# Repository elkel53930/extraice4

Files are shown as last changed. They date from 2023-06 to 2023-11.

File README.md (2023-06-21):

# ExtraICE4

ExtraICE4 is a competition robot called Micromouse.

For more information on Micromouse competitions, please see the [website](https://www.ntf.or.jp/) of the New Technology Foundation.

## Hardware

- 3DCAD data by Fusion360 : https://t.co/qPmjVBnEnc
  - STL file for 3D printing : under `mecha` directory
- Schematic and PCB design by KiCad7 : under `kicad/extraice` directory

## Firmware

The firmware is written by Rust language.

See [The Rust on ESP Book](https://esp-rs.github.io/book/) for instructions on how to set up the development environment.

The firmware is located under `fsw` directory. This directory is a sub-module, which is actually the micromouse-esp32 repository.

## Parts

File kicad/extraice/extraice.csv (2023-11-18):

# | Reference | Qty | Value | Footprint | DNP
1 | C1, C10 | 2 | 1608 35V 1uF | Capacitor_SMD:C_0603_1608Metric
2 | C2, C18, C21 | 3 | 2012 35V 10uF | Capacitor_SMD:C_0805_2012Metric
3 | C3, C5, C7, C8, C9, C12, C14, C15, C16, C19 | 10 | 0603 50V 0.1uF | Capacitor_SMD:C_0201_0603Metric
4 | C4 | 1 | 3225 25V 22uF | Capacitor_SMD:C_1210_3225Metric
5 | C11, C13 | 2 | 1005 N/M | Capacitor_SMD:C_0402_1005Metric
6 | D1, D2, D3, D4 | 4 | OSI5FU3A11C | Micromouse:OSI5FU3A11C
7 | D5 | 1 | 1608 R LED | LED_SMD:LED_0603_1608Metric
8 | D6 | 1 | 1608 G LED | LED_SMD:LED_0603_1608Metric
9 | D7 | 1 | 1608 B LED | LED_SMD:LED_0603_1608Metric
10 | H1, H2, H3, H4 | 4 | Φ1.4 | Micromouse:Hole1.4
11 | J1 | 1 | Conn_01x02 | Micromouse:B2B-ZH
12 | J3, J6 | 2 | EncSide | Micromouse:EncoderTerminal
13 | J4, J7 | 2 | MainSide | Micromouse:EncoderTerminal
14 | J5 | 1 | Conn_01x05 | Connector_PinHeader_1.27mm:PinHeader_1x05_P1.27mm_Vertical
15 | J8, J9, J10 | 3 | Conn_01x02 | Micromouse:MotorPad
16 | Q1, Q2, Q3, Q4 | 4 | L-31ROPT1C | Micromouse:OSI5FU3A11C
17 | R1, R7, R10, R12 | 4 | 0603 470 1% | Resistor_SMD:R_0201_0603Metric
18 | R2, R8, R14, R15, R16 | 5 | 0603 10k | Resistor_SMD:R_0201_0603Metric
19 | R4, R5, R6, R9 | 4 | 0603 1k | Resistor_SMD:R_0201_0603Metric
20 | R11 | 1 | 0603 6.2 | Resistor_SMD:R_0201_0603Metric
21 | R13 | 1 | 0603 22k | Resistor_SMD:R_0201_0603Metric
22 | SW1 | 1 | PCM12SMTR | Button_Switch_SMD:SW_SPDT_PCM12
23 | SW2 | 1 | B3U-1000P | Button_Switch_SMD:SW_SPST_B3U-1000P
24 | U1 | 1 | DG2034EDN | Library:QFN-12-1EP_3x3mm_P0.5_EP1.15x1.15
25 | U2 | 1 | BCR421 | Library:SOT-26
26 | U3 | 1 | MUN12AD01-SG | Library:MUN12AD01-SG
27 | U4 | 1 | MB85RC64TA | Library:LCC-8P-M04
28 | U5 | 1 | LSM6DSR | Package_LGA:Bosch_LGA-14_3x2.5mm_P0.5mm
29 | U6 | 1 | XC6221B302GR | Package_TO_SOT_SMD:SOT-23-5
30 | U7 | 1 | ESP32-S3-FN8 | Package_DFN_QFN:QFN-56-1EP_7x7mm_P0.4mm_EP4x4mm
31 | U8, U12 | 2 | AS5047D | Package_SO:TSSOP-14_4.4x5mm_P0.65mm
32 | U9, U10, U11 | 3 | DRV8837C | Package_SON:WSON-8-1EP_2x2mm_P0.5mm_EP0.9x1.6mm
33 | X1 | 1 | 830108208709 | Oscillator:Oscillator_SMD_ECS_2520MV-xxx-xx-4Pin_2.5x2.0mm

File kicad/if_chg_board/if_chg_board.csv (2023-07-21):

Source: | C:\dev\extraice4\kicad\if_chg_board\if_chg_board.kicad_sch
Date: | 2023/07/21 8:57:58
Tool: | Eeschema (7.0.0)
Generator: | C:\Program Files\KiCad\7.0\bin\scripting\plugins/bom_csv_grouped_by_value.py
Component Count: | 47
Collated Components:
Item | Qty | Reference(s) | Value | LibPart | Footprint | Datasheet | DNP
1 | 2 | C1, C4 | 3225 22uF | Device:C_Small | Capacitor_SMD:C_1210_3225Metric | ~
2 | 4 | C2, C3, C5, C6 | 1608 4.7u | Device:C_Small | Capacitor_SMD:C_0603_1608Metric | ~
3 | 3 | C7, C8, C9 | 1608 0.1u | Device:C_Small | Capacitor_SMD:C_0603_1608Metric | ~
4 | 2 | D1, D2 | LED RED | Device:LED | LED_SMD:LED_0603_1608Metric | ~
5 | 1 | D3 | SP0503BAHT | Power_Protection:SP0503BAHT | Package_TO_SOT_SMD:SOT-143 | http://www.littelfuse.com/~/media/files/littelfuse/technical%20resources/documents/data%20sheets/sp05xxba.pdf
6 | 1 | D4 | BAT760-7 | Device:D_Schottky | Diode_SMD:D_SOD-323 | ~
7 | 1 | D5 | LED GREEN | Device:LED | LED_SMD:LED_0603_1608Metric | ~
8 | 4 | H1, H2, H3, H4 | Φ3.2 M3 | Mechanical:MountingHole | MountingHole:MountingHole_3.2mm_M3 | ~
9 | 1 | J1 | USB_B_Micro | Connector:USB_B_Micro | Connector_USB:USB_Micro-B_Molex-105017-0001 | ~
10 | 2 | J2, J3 | B2B-ZH | Connector_Generic:Conn_01x02 | Library:B2B-ZH | ~
11 | 1 | J4 | Conn_01x05 | Connector_Generic:Conn_01x05 | Connector_PinHeader_1.27mm:PinHeader_1x05_P1.27mm_Vertical | ~
12 | 1 | J5 | B2B-ZH | Connector_Generic:Conn_01x02 | Connector_PinHeader_2.54mm:PinHeader_1x02_P2.54mm_Vertical | ~
13 | 2 | Q1, Q2 | SS8050-G | Device:Q_NPN_BEC | Package_TO_SOT_SMD:SOT-23 | ~
14 | 4 | R1, R2, R3, R4 | 1608 1.2K | Device:R | Resistor_SMD:R_0603_1608Metric | ~
15 | 2 | R5, R7 | 1608 2K | Device:R | Resistor_SMD:R_0603_1608Metric | ~
16 | 1 | R6 | 1608 0 | Device:R | Resistor_SMD:R_0603_1608Metric | ~
17 | 1 | R8 | 1608 10K NC | Device:R | Resistor_SMD:R_0603_1608Metric | ~
18 | 3 | R9, R10, R11 | 1608 10K | Device:R | Resistor_SMD:R_0603_1608Metric | ~
19 | 2 | SW1, SW2 | B3U-1000P | Switch:SW_Push | Button_Switch_SMD:SW_SPST_B3U-1000P | ~
20 | 4 | TP1, TP2, TP3, TP4 | ~ | Connector:TestPoint | TestPoint:TestPoint_Pad_D1.5mm | ~
21 | 1 | TP5 | ~ | Connector:TestPoint | Connector_PinHeader_2.54mm:PinHeader_1x01_P2.54mm_Vertical | ~
22 | 1 | U1 | AMS1117-3.3 | Regulator_Linear:AMS1117-3.3 | Package_TO_SOT_SMD:SOT-223-3_TabPin2 | http://www.advanced-monolithic.com/pdf/ds1117.pdf
23 | 2 | U2, U3 | LTC4054ES5-4.2 | Battery_Management:LTC4054ES5-4.2 | Package_TO_SOT_SMD:TSOT-23-5 | https://www.analog.com/media/en/technical-documentation/data-sheets/405442xf.pdf
24 | 1 | U4 | CP2102-GM | Interface_USB:CP2102N-Axx-xQFN28 | Package_DFN_QFN:QFN-28-1EP_5x5mm_P0.5mm_EP3.35x3.35mm | https://www.silabs.com/documents/public/data-sheets/cp2102n-datasheet.pdf

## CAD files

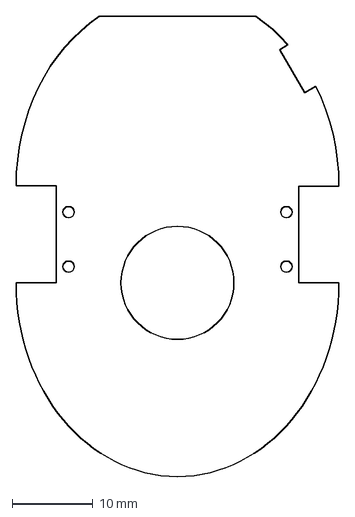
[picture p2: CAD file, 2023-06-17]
kicad/extraice/mainboard.dxf
40.0 x 57.0 mm

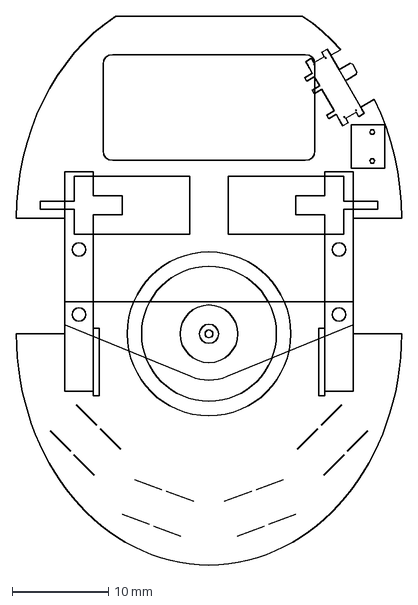
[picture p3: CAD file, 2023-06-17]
kicad/extraice/mainboard_position.dxf
40.0 x 57.0 mm

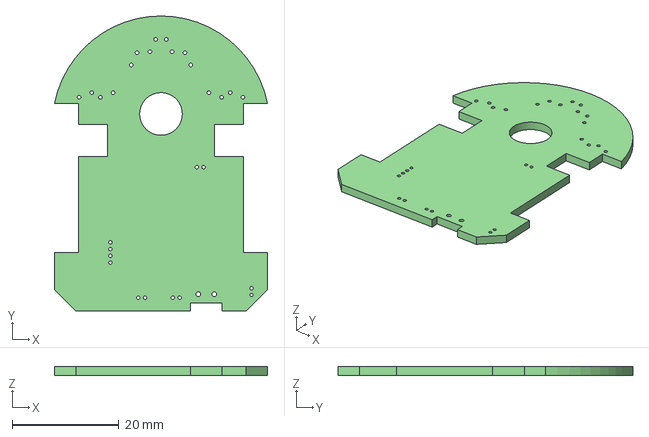
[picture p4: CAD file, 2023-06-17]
kicad/extraice/extraice.step
40.0 x 55.4 x 1.60 mm

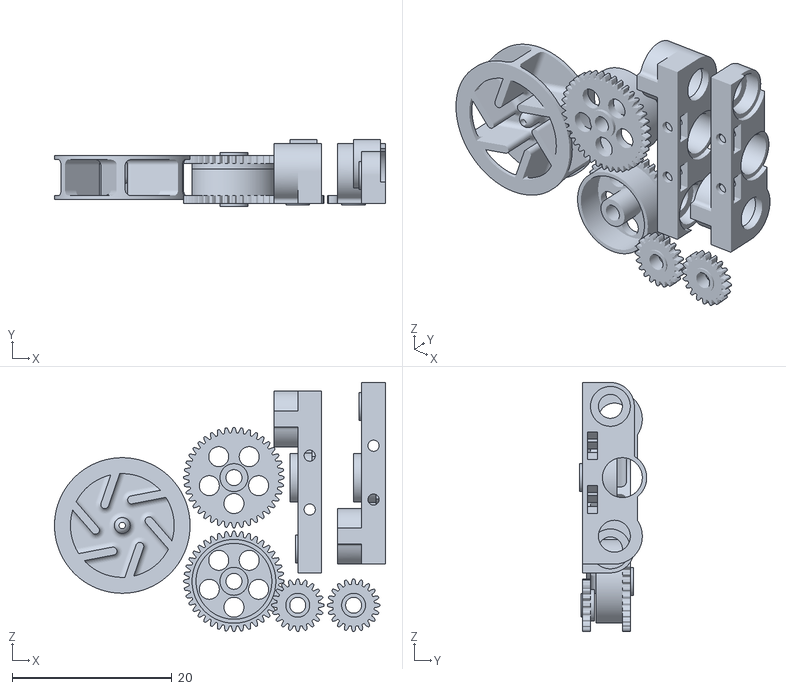
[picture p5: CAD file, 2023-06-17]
mecha/parts_set.stl
41.5 x 8.45 x 31.2

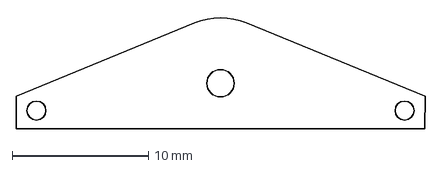
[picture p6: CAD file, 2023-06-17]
kicad/extraice/vacboard.dxf
30.0 x 8.26 mm

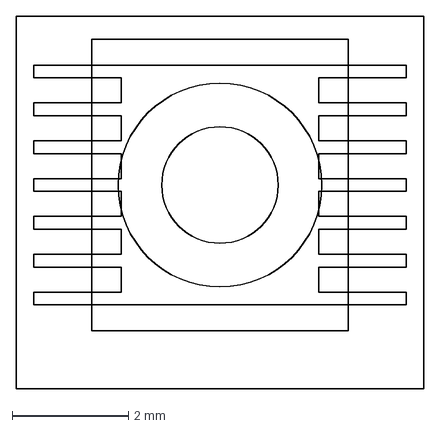
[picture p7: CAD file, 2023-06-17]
kicad/extraice/encoder.dxf
7.00 x 6.40 mm

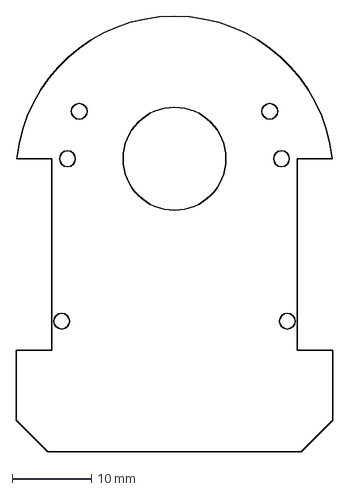
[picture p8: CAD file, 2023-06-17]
kicad/extraice/bottomboard.dxf
40.0 x 55.0 mm

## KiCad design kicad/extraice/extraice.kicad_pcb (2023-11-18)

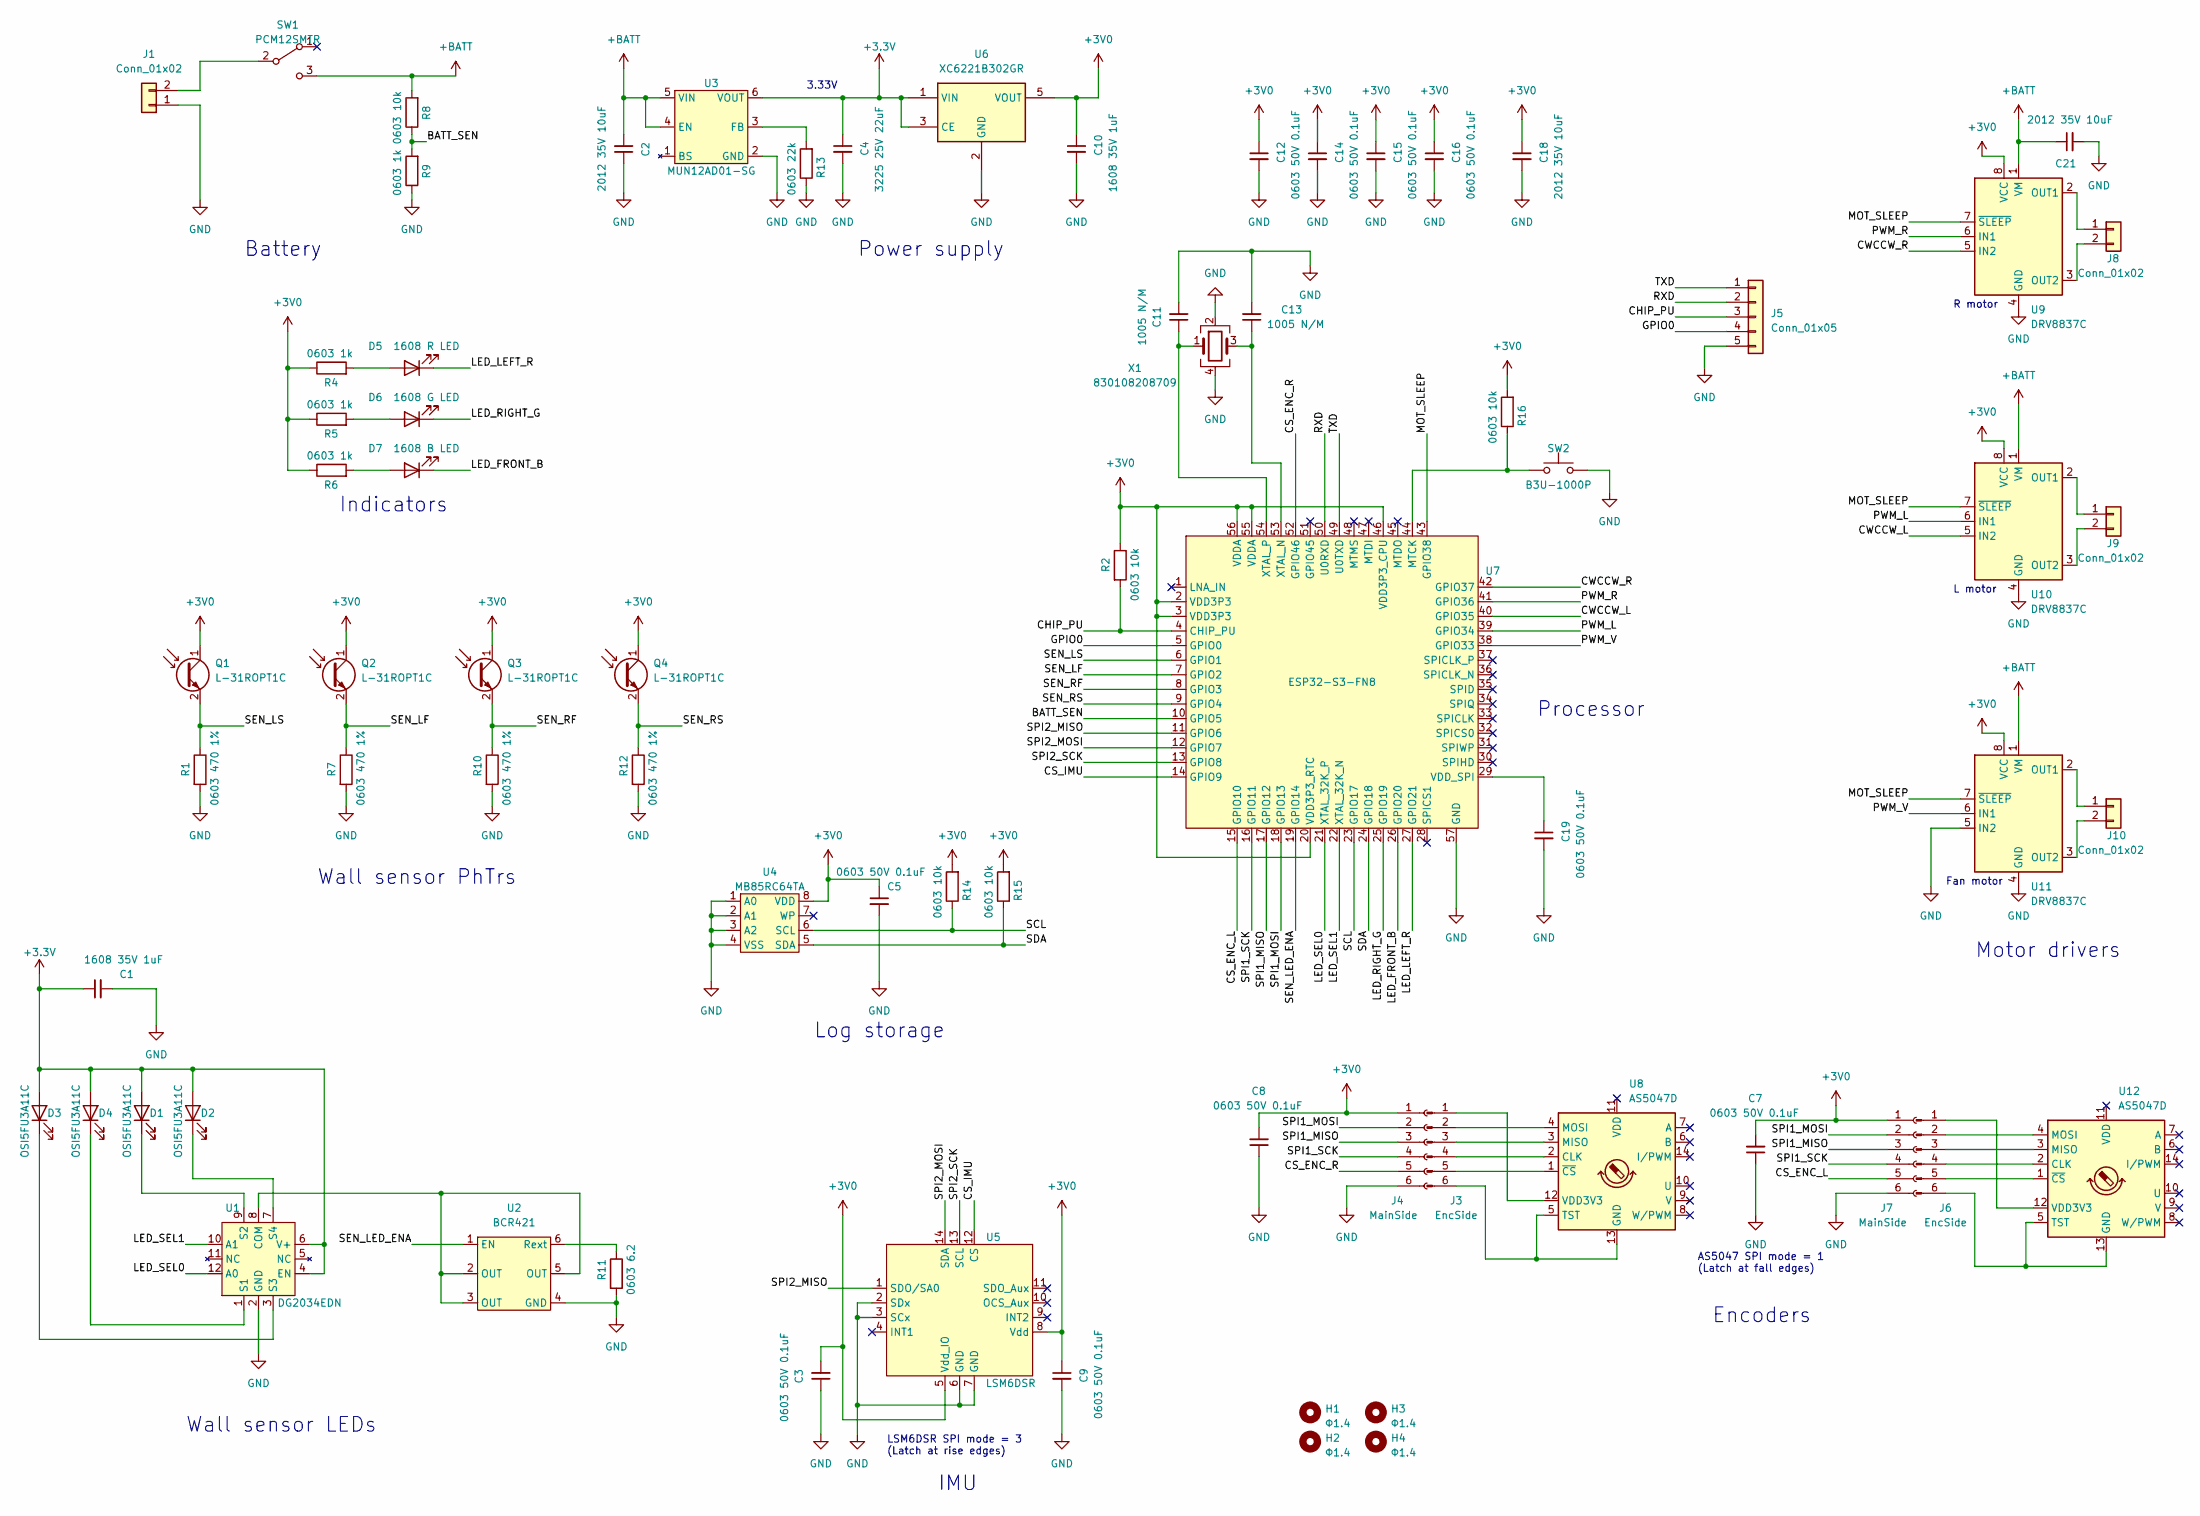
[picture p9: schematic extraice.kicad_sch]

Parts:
C1, C10: 1608 35V 1uF; C_0603_1608Metric
C2, C18, C21: 2012 35V 10uF; C_0805_2012Metric
C3, C5, C7, C8, C9, C12, C14, C15, C16, C19: 0603 50V 0.1uF; C_0201_0603Metric
C4: 3225 25V 22uF; C_1210_3225Metric
C11, C13: 1005 N/M; C_0402_1005Metric
D1, D2, D3, D4: OSI5FU3A11C
D5: 1608 R LED; LED_0603_1608Metric
D6: 1608 G LED; LED_0603_1608Metric
D7: 1608 B LED; LED_0603_1608Metric
H1, H2, H3, H4: Φ1.4; Hole1.4
J1: Conn_01x02; B2B-ZH
J3, J6: EncSide; EncoderTerminal
J4, J7: MainSide; EncoderTerminal
J5: Conn_01x05; PinHeader_1x05_P1.27mm_Vertical
J8, J9, J10: Conn_01x02; MotorPad
Q1, Q2, Q3, Q4: L-31ROPT1C; OSI5FU3A11C
R1, R7, R10, R12: 0603 470 1%; R_0201_0603Metric
R2, R8, R14, R15, R16: 0603 10k; R_0201_0603Metric
R4, R5, R6, R9: 0603 1k; R_0201_0603Metric
R11: 0603 6.2; R_0201_0603Metric
R13: 0603 22k; R_0201_0603Metric
SW1: PCM12SMTR; SW_SPDT_PCM12
SW2: B3U-1000P; SW_SPST_B3U-1000P
U1: DG2034EDN; QFN-12-1EP_3x3mm_P0.5_EP1.15x1.15
U2: BCR421; SOT-26
U3: MUN12AD01-SG
U4: MB85RC64TA; LCC-8P-M04
U5: LSM6DSR; Bosch_LGA-14_3x2.5mm_P0.5mm
U6: XC6221B302GR; SOT-23-5
U7: ESP32-S3-FN8; QFN-56-1EP_7x7mm_P0.4mm_EP4x4mm
U8, U12: AS5047D; TSSOP-14_4.4x5mm_P0.65mm
U9, U10, U11: DRV8837C; WSON-8-1EP_2x2mm_P0.5mm_EP0.9x1.6mm
X1: 830108208709; Oscillator_SMD_ECS_2520MV-xxx-xx-4Pin_2.5x2.0mm

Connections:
+3.3V: C1.1, C4.1, D1.2 (A), D2.2 (A), D3.2 (A), D4.2 (A), U1.4 (EN), U1.6 (V+), U3.6 (VOUT), U6.1 (VIN), U6.3 (CE)
+3V0: C3.2, C5.1, C7.2, C8.2, C9.1, C10.1, C12.1, C14.1, C15.1, C16.1, C18.1, J4.1, J7.1, Q1.1 (C), Q2.1 (C), Q3.1 (C), Q4.1 (C), R2.1, R4.1, R5.1, R6.1, R14.2, R15.2, R16.2, U4.8 (VDD), U5.5 (Vdd_IO), U5.8 (Vdd), U6.5 (VOUT), U7.2 (VDD3P3), U7.3 (VDD3P3), U7.20 (VDD3P3_RTC), U7.46 (VDD3P3_CPU), U7.55 (VDDA), U7.56 (VDDA), U9.8 (VCC), U10.8 (VCC), U11.8 (VCC)
+BATT: C2.2, C21.1, R8.2, SW1.3 (C), U3.4 (EN), U3.5 (VIN), U9.1 (VM), U10.1 (VM), U11.1 (VM)
/BATT_SEN: R8.1, R9.2, U7.10 (GPIO5)
/CHIP_PU: J5.3, R2.2, U7.4 (CHIP_PU)
/CS_ENC_L: J7.5, U7.15 (GPIO10)
/CS_ENC_R: J4.5, U7.52 (GPIO46)
/CS_IMU: U5.12 (CS), U7.14 (GPIO9)
/CWCCW_L: U7.40 (GPIO35), U10.5 (IN2)
/CWCCW_R: U7.42 (GPIO37), U9.5 (IN2)
/GPIO0: J5.4, U7.5 (GPIO0)
/LED_FRONT_B: D7.1 (K), U7.26 (GPIO20)
/LED_LEFT_R: D5.1 (K), U7.27 (GPIO21)
/LED_RIGHT_G: D6.1 (K), U7.25 (GPIO19)
/LED_SEL0: U1.12 (A0), U7.21 (XTAL_32K_P)
/LED_SEL1: U1.10 (A1), U7.22 (XTAL_32K_N)
/MOT_SLEEP: U7.43 (GPIO38), U9.7 (~SLEEP), U10.7 (~SLEEP), U11.7 (~SLEEP)
/PWM_L: U7.39 (GPIO34), U10.6 (IN1)
/PWM_R: U7.41 (GPIO36), U9.6 (IN1)
/PWM_V: U7.38 (GPIO33), U11.6 (IN1)
/RXD: J5.2, U7.50 (U0RXD)
/SCL: R14.1, U4.6 (SCL), U7.23 (GPIO17)
/SDA: R15.1, U4.5 (SDA), U7.24 (GPIO18)
/SEN_LED_ENA: U2.1 (EN), U7.19 (GPIO14)
/SEN_LF: Q2.2 (E), R7.1, U7.7 (GPIO2)
/SEN_LS: Q1.2 (E), R1.1, U7.6 (GPIO1)
/SEN_RF: Q3.2 (E), R10.1, U7.8 (GPIO3)
/SEN_RS: Q4.2 (E), R12.1, U7.9 (GPIO4)
/SPI1_MISO: J4.3, J7.3, U7.17 (GPIO12)
/SPI1_MOSI: J4.2, J7.2, U7.18 (GPIO13)
/SPI1_SCK: J4.4, J7.4, U7.16 (GPIO11)
/SPI2_MISO: U5.1 (SDO/SA0), U7.11 (GPIO6)
/SPI2_MOSI: U5.14 (SDA), U7.12 (GPIO7)
/SPI2_SCK: U5.13 (SCL), U7.13 (GPIO8)
/TXD: J5.1, U7.49 (U0TXD)
GND: C1.2, C2.1, C3.1, C4.2, C5.2, C7.1, C8.1, C9.2, C10.2, C11.2, C12.2, C13.2, C14.2, C15.2, C16.2, C18.2, C19.2, C21.2, J1.1, J4.6, J5.5, J7.6, R1.2, R7.2, R9.1, R10.2, R11.2, R12.2, R13.1, SW2.2, U1.2 (GND), U2.4 (GND), U3.2 (GND), U4.1 (A0), U4.2 (A1), U4.3 (A2), U4.4 (VSS), U5.2 (SDx), U5.3 (SCx), U5.6 (GND), U5.7 (GND), U6.2 (GND), U7.57 (GND), U9.4 (GND), U9.9 (GND), U10.4 (GND), U10.9 (GND), U11.4 (GND), U11.5 (IN2), U11.9 (GND), X1.2, X1.4
unnamed: D1.1 (K), U1.9 (S2)
unnamed: D2.1 (K), U1.7 (S4)
unnamed: D3.1 (K), U1.3 (S3)
unnamed: D4.1 (K), U1.1 (S1)
unnamed: D5.2 (A), R4.2
unnamed: D6.2 (A), R5.2
unnamed: D7.2 (A), R6.2
unnamed: J1.2, SW1.2 (B)
unnamed: J3.1, U8.12 (VDD3V3)
unnamed: J3.2, U8.4 (MOSI)
unnamed: J3.3, U8.3 (MISO)
unnamed: J3.4, U8.2 (CLK)
unnamed: J3.5, U8.1 (~CS)
unnamed: J3.6, U8.5 (TST), U8.13 (GND)
unnamed: J6.1, U12.12 (VDD3V3)
unnamed: J6.2, U12.4 (MOSI)
unnamed: J6.3, U12.3 (MISO)
unnamed: J6.4, U12.2 (CLK)
unnamed: J6.5, U12.1 (~CS)
unnamed: J6.6, U12.5 (TST), U12.13 (GND)
unnamed: J8.1, U9.2 (OUT1)
unnamed: J8.2, U9.3 (OUT2)
unnamed: J9.1, U10.2 (OUT1)
unnamed: J9.2, U10.3 (OUT2)
unnamed: J10.1, U11.2 (OUT1)
unnamed: J10.2, U11.3 (OUT2)
unnamed: U1.8 (COM), U2.2 (OUT), U2.3 (OUT), U2.5 (OUT)
unnamed: R11.1, U2.6 (Rext)
unnamed: R13.2, U3.3 (FB)
unnamed: R16.1, SW2.1, U7.44 (MTCK)
unnamed: C19.1, U7.29 (VDD_SPI)
unnamed: C13.1, U7.53 (XTAL_N), X1.3
unnamed: C11.1, U7.54 (XTAL_P), X1.1

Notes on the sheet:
Wall sensor LEDs
L motor
R motor
Indicators
Motor drivers
Power supply
3.33V
LSM6DSR SPI mode = 3 (Latch at rise edges)
Wall sensor PhTrs
Processor
AS5047 SPI mode = 1 (Latch at fall edges)
Log storage
Battery
Encoders
IMU
Fan motor

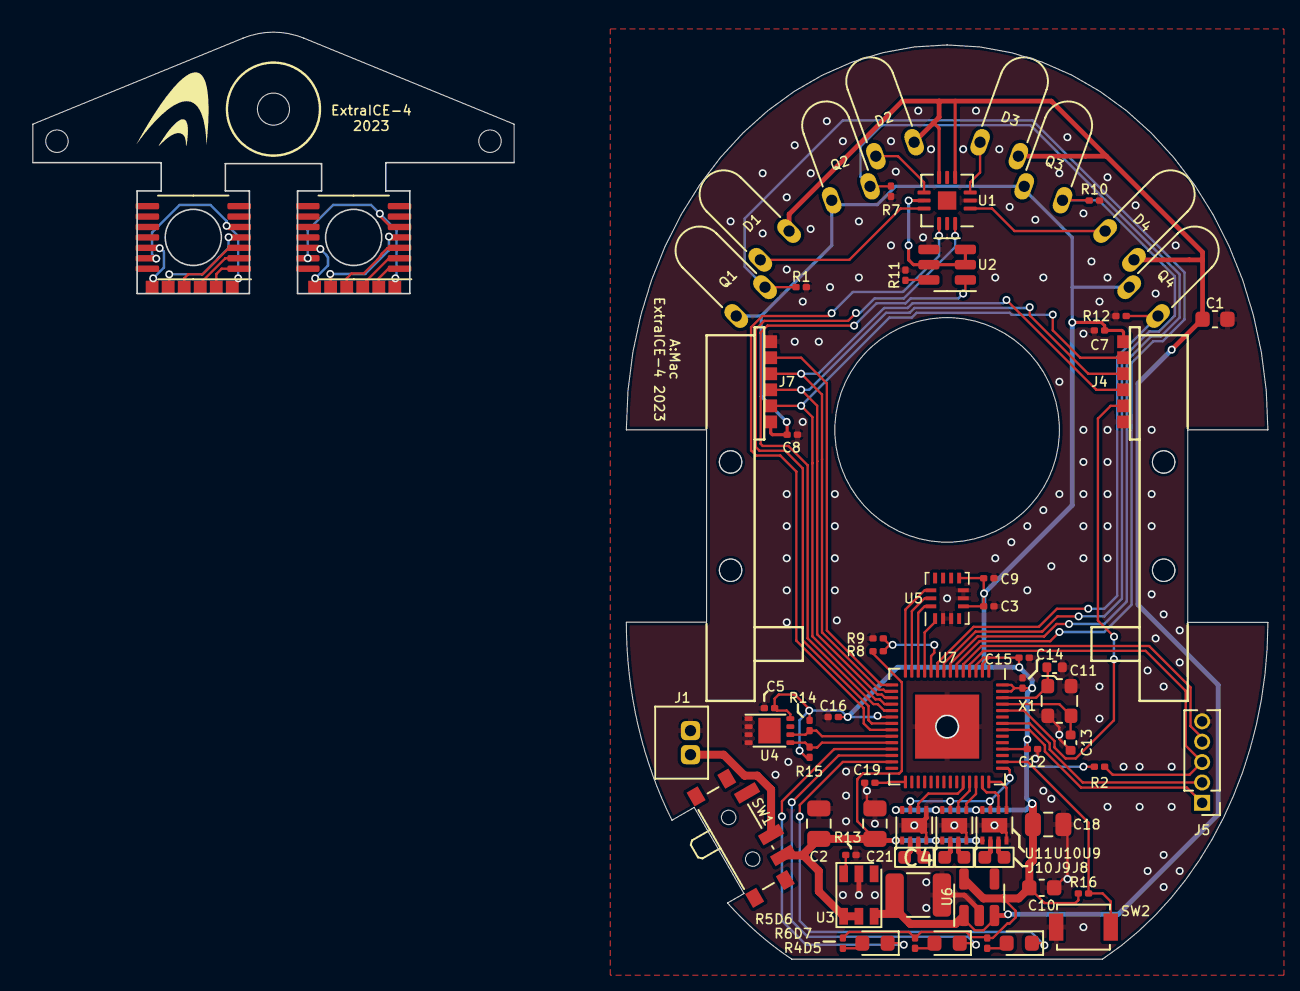
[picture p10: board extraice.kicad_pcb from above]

Board: 2 copper layers, 40.0 x 57.0 mm, 72 parts (0 on the bottom side), 69 nets.

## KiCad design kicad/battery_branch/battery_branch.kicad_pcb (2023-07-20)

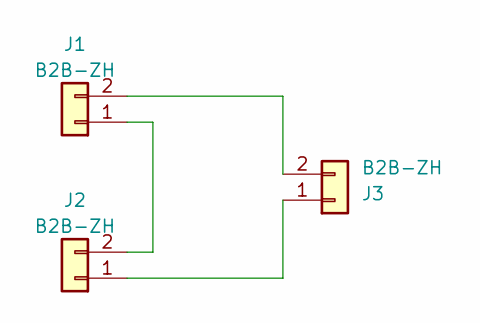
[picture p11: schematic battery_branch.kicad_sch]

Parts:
J1, J2, J3: B2B-ZH

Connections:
unnamed: J1.1, J2.2
unnamed: J1.2, J3.2
unnamed: J2.1, J3.1

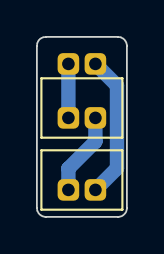
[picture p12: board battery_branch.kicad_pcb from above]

Board: 2 copper layers, 5.0 x 10.0 mm, 3 parts (1 on the bottom side), 3 nets.

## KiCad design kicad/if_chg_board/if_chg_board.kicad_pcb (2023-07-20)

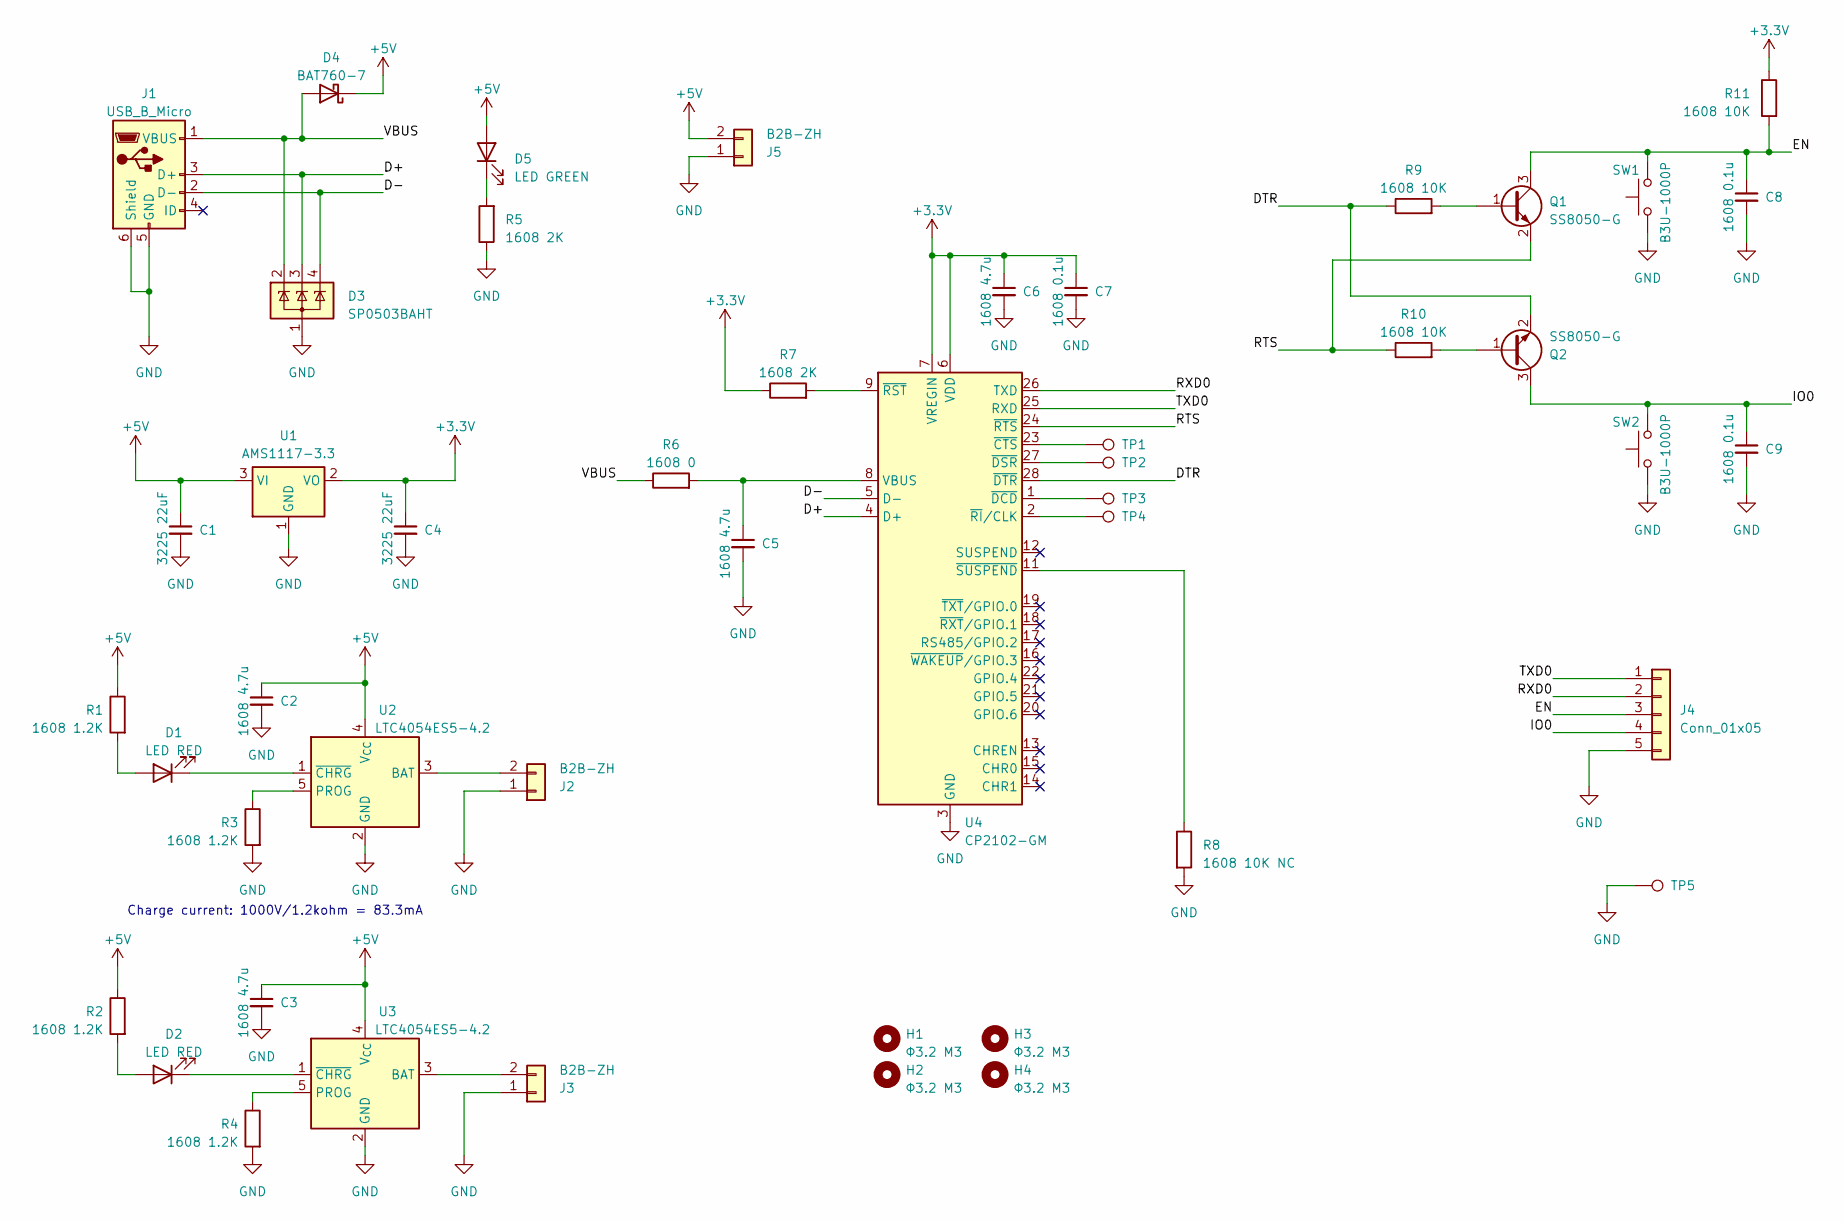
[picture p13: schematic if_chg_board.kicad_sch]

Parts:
C1, C4: 3225 22uF; C_1210_3225Metric
C2, C3, C5, C6: 1608 4.7u; C_0603_1608Metric
C7, C8, C9: 1608 0.1u; C_0603_1608Metric
D1, D2: LED RED; LED_0603_1608Metric
D3: SP0503BAHT; SOT-143
D4: BAT760-7; D_SOD-323
D5: LED GREEN; LED_0603_1608Metric
H1, H2, H3, H4: Φ3.2 M3; MountingHole_3.2mm_M3
J1: USB_B_Micro; USB_Micro-B_Molex-105017-0001
J2, J3: B2B-ZH
J4: Conn_01x05; PinHeader_1x05_P1.27mm_Vertical
J5: B2B-ZH; PinHeader_1x02_P2.54mm_Vertical
Q1, Q2: SS8050-G; SOT-23
R1, R2, R3, R4: 1608 1.2K; R_0603_1608Metric
R5, R7: 1608 2K; R_0603_1608Metric
R6: 1608 0; R_0603_1608Metric
R8: 1608 10K NC; R_0603_1608Metric
R9, R10, R11: 1608 10K; R_0603_1608Metric
SW1, SW2: B3U-1000P; SW_SPST_B3U-1000P
TP1, TP2, TP3, TP4: TestPoint_Pad_D1.5mm
TP5: PinHeader_1x01_P2.54mm_Vertical
U1: AMS1117-3.3; SOT-223-3_TabPin2
U2, U3: LTC4054ES5-4.2; TSOT-23-5
U4: CP2102-GM; QFN-28-1EP_5x5mm_P0.5mm_EP3.35x3.35mm

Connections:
+3.3V: C4.1, C6.1, C7.1, R7.1, R11.1, U1.2 (VO), U4.6 (VDD), U4.7 (VREGIN)
+5V: C1.1, C2.1, C3.1, D4.1 (K), D5.2 (A), J5.2, R1.1, R2.1, U1.3 (VI), U2.4 (V_{CC}), U3.4 (V_{CC})
/D+: D3.3 (K), J1.3 (D+), U4.4 (D+)
/D-: D3.4 (K), J1.2 (D-), U4.5 (D-)
/DTR: Q2.2 (E), R9.1, U4.28 (~DTR)
/EN: C8.1, J4.3, Q1.3 (C), R11.2, SW1.2
/IO0: C9.1, J4.4, Q2.3 (C), SW2.2
/RTS: Q1.2 (E), R10.1, U4.24 (~RTS)
/RXD0: J4.2, U4.26 (TXD)
/TXD0: J4.1, U4.25 (RXD)
/VBUS: D3.2 (K), D4.2 (A), J1.1 (VBUS), R6.1
GND: C1.2, C2.2, C3.2, C4.2, C5.2, C6.2, C7.2, C8.2, C9.2, D3.1 (A), J1.5 (GND), J1.6 (Shield), J2.1, J3.1, J4.5, J5.1, R3.2, R4.2, R5.1, R8.2, SW1.1, SW2.1, TP5.1, U1.1 (GND), U2.2 (GND), U3.2 (GND), U4.3 (GND), U4.29 (GND)
unnamed: D1.2 (A), R1.2
unnamed: D1.1 (K), U2.1 (~CHRG)
unnamed: D2.2 (A), R2.2
unnamed: D2.1 (K), U3.1 (~CHRG)
unnamed: D5.1 (K), R5.2
unnamed: J2.2, U2.3 (BAT)
unnamed: J3.2, U3.3 (BAT)
unnamed: Q1.1 (B), R9.2
unnamed: Q2.1 (B), R10.2
unnamed: R3.1, U2.5 (PROG)
unnamed: R4.1, U3.5 (PROG)
unnamed: C5.1, R6.2, U4.8 (VBUS)
unnamed: TP1.1, U4.23 (~CTS)
unnamed: TP3.1, U4.1 (~DCD)
unnamed: TP2.1, U4.27 (~DSR)
unnamed: TP4.1, U4.2 (~RI/CLK)
unnamed: R7.2, U4.9 (~RST)
unnamed: R8.1, U4.11 (~SUSPEND)

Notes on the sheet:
Charge current: 1000V/1.2kohm = 83.3mA

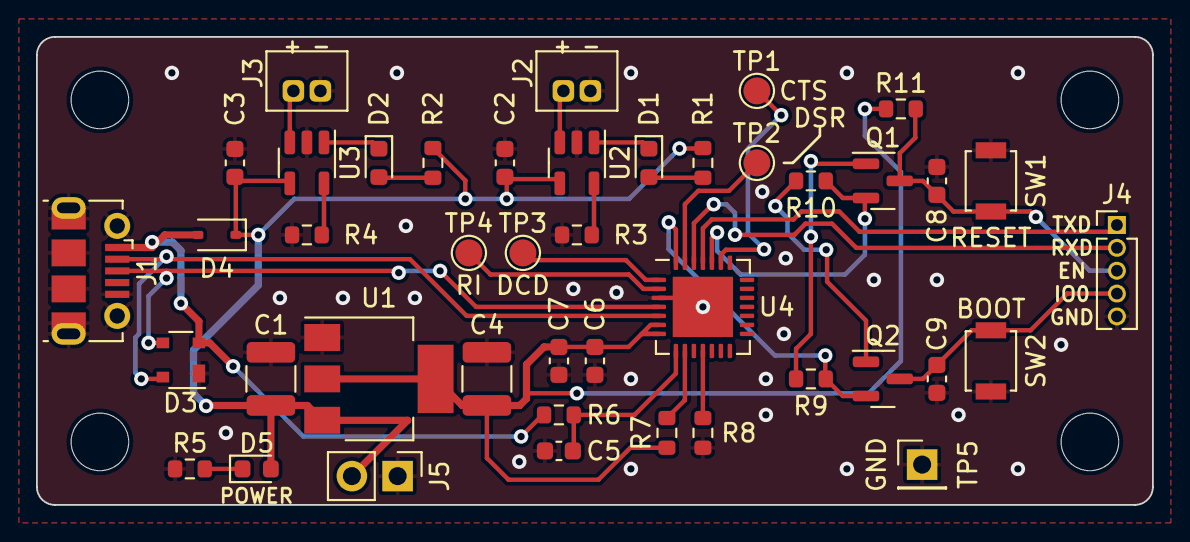
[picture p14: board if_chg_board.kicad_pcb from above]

Board: 2 copper layers, 62.0 x 26.0 mm, 47 parts (0 on the bottom side), 30 nets.

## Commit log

2023-06-17 Add mechanical parts to be output by 3D printer
    [parts_set.stl]
2023-07-07 Fix problems identified during implementation
    - ESP32 supports only crystal oscillator, not resonator.
    - The package and capacitance of capacitor C1 were incorrect.
    - Fix a ESP32 pin name. GPIO15 -> GPIO14.
    [extraice.csv, extraice.kicad_pcb, extraice.kicad_sch]
2023-07-20 Interface & charning board
    [if_chg_board.kicad_pcb, if_chg_board.kicad_sch]
2023-07-20 Update if_chg_board
    [if_chg_board.kicad_pcb, if_chg_board.kicad_sch]
2023-07-20 Add battery branch board
    [battery_branch.kicad_pcb, battery_branch.kicad_sch]
2023-07-20 Add .gitignore for KiCad (from https://github.com/github/gitignore/blob/main/KiCad.gitignore)
2023-07-21 Add parts list for if_chg_board
    [if_chg_board.csv]
2023-11-15 Fix battery charge current
    [if_chg_board.kicad_sch]
2023-11-18 Remove unnecessary wiring
    [extraice.kicad_sch]
2023-11-18 Add a pull-up register to the CHIP-PU pin.
    [extraice.csv, extraice.kicad_pcb, extraice.kicad_sch]
